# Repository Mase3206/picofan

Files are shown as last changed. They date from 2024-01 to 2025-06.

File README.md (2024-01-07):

# picofan
Picofan is a Raspberry Pi Pico-based fan controller supporting PWM fans, speed measurement, and automatic speed adjustment. A RP2040-based PCB will be published in the future.

## Hardware Requirements

### Fans

Currenly, only PWM fans are supported due to their ease of digital control. Support for voltage-controlled fans may be implemented in the future.

picofan is fan voltage-agnostic by controlling fan power with individual transistors. <!-- TODO: add info about board vcc voltages when PCB and schematics are added to repo -->

### Temperature Sensors

Fan speed can be set to adjust automatically via a default or user-defined curve with feedback from one or more temperature sensors. Only analogue sensors are supported at this time, and they must be connected to a static serial shift register, such as the [Texas Instruments CD4021B](https://www.ti.com/product/CD4021B#pps). The RP2040 has four ADCs, three of which are available to the user on the Pico; one is reserved for the on-board temperature sensor.

### Control

picofan can be controlled by a Raspberry Pi 2 or later at the moment, but support for any device with a UART interface is planned. For my development, I am using a Raspberry Pi 3b. 

## Software

picofan has two software components:
1. Pico code, written in MicroPython
2. Companion device code, written in standard Python 3

The two devices communicate via a [custom protocol](./docs/protocol.md) over UART0 and use unique addresses to identify the command sender and recipient.

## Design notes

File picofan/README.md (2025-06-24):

This folder holds the pico-side of things.

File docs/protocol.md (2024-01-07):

[Return to README](../README.md)

# Initialization Protocol

Sensor and device configuration on the Pico(s) is done through Yaml files on the companion device. Once all devices are configured in companion.py, it will communicate with the Pico(s) to initialize them. The following is an example init message:

`fd  01 02 01  01 01  04 05 06  88 fe  00 00 00 00 00`

- `fd` - begin msg
- `01` - tx addr
- `02` - rx addr
- `01` - initialize device command
- `01` - sensor/device type
- `01` - sensor/device addr
- Sensor/device parameters:
	- Fan: (this example)
		- `04` - Power control pin (out)
		- `05` - PWM pin (out)
		- `06` - Tachometer pin (in)
	- Temperature:
		- `1f` - Pico pin connected to shift register (out)
		- `01` - pin on shift register (out)
- `88` - checksum
- `fe` - end msg
- `00 ...` message filler

# Control Protocol

picofan uses a custom protocol with a simple checksum for communicating between the companion and pico(s).

Example message: `fd  01 02 03  01 01 00   7a fe  00 00 00 00 00 00 00`
- `fd` - begin msg
- `01` - tx addr
- `02` - rx addr
- `03` - command (init, init ack, set, get)
	- `01` = init
	- `02` = set
	- `03` = get
- `01` - sensor/device type (fan, temp, etc.)
	- `01` = fan
	- `02` = temp
- `01` - sensor/device addr 
- `00` - value to set/get (speed, temperature, etc.)
	- Fans:
		- `00` = speed
	- Thermal probes
		- `00` = temperature
- `7a` - checksum
- `fe` - end msg
- `00 ...` - message filler

## Checksum

The checksum is calculated in a similar manner to UPC codes:
1. Sum all evens, then multiply by 77. <sup>1</sup>
2. Sum all odds.
3. Take the mod 255 of the sum of both components. <sup>2</sup>
4. Subtract 255 by the previous result. This is your checksum. <sup>2</sup>

> [!NOTE]
> - [1] UPC codes multiply by 3.
> - [2] UPC codes use mod 10 and subtract 10 by the result.

# Examples

I have provided example messages and an ImHex Pattern Language parser in the `docs/examples` directory.

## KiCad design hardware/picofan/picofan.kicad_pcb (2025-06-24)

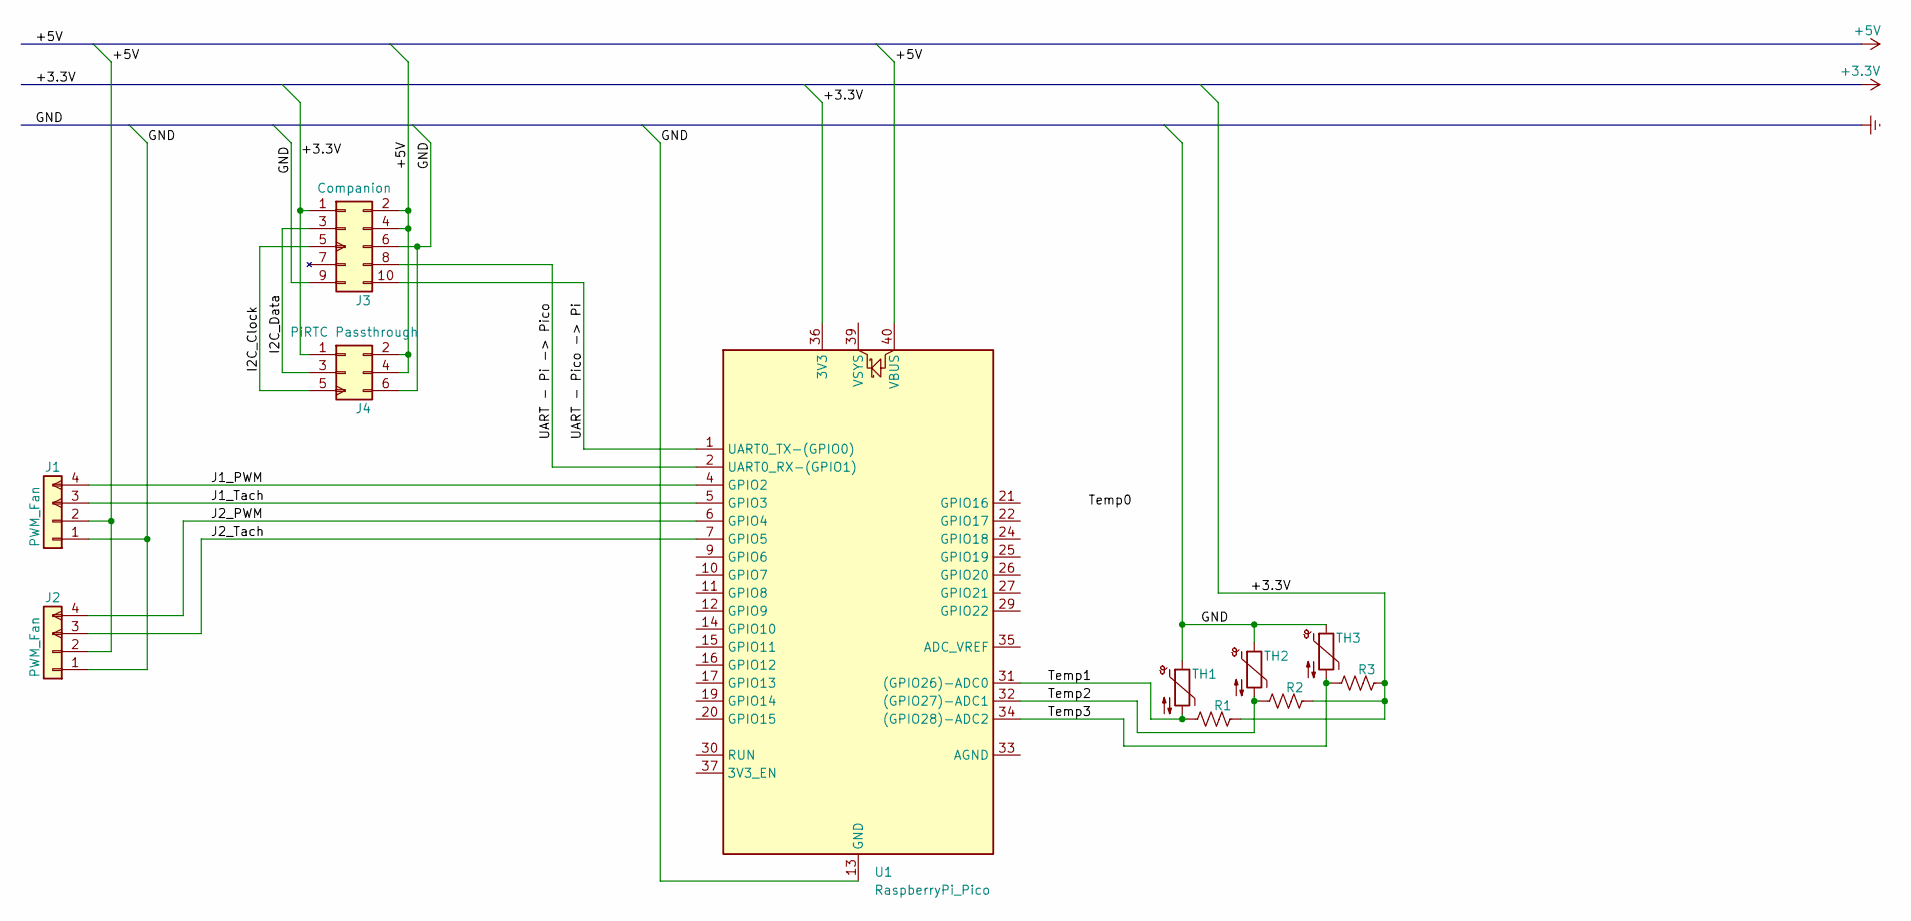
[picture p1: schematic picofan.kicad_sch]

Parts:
J1, J2: PWM_Fan; FanPinHeader_1x04_P2.54mm_Vertical
J3: Companion; IDC-Header_2x05_P2.54mm_Vertical
J4: PiRTC Passthrough; IDC-Header_2x03_P2.54mm_Vertical
R1, R2, R3: R_US; R_Axial_DIN0204_L3.6mm_D1.6mm_P5.08mm_Horizontal
TH1, TH2, TH3: Thermistor_NTC; R_Axial_DIN0204_L3.6mm_D1.6mm_P2.54mm_Vertical
U1: RaspberryPi_Pico; RaspberryPi_Pico_Common

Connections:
+3.3V: J3.1 (+3.3V), J4.1 (+3.3V), R1.2, R2.2, R3.2, U1.36 (3V3)
+5V: J1.2 (V_in), J2.2 (V_in), J3.2 (+5V), J3.4 (+5V), J4.2 (+5V), J4.4 (+5V), U1.40 (VBUS)
/I2C_Clock: J3.5 (I2C_Clk), J4.5 (I2C_Clk)
/I2C_Data: J3.3 (I2C_Data), J4.3 (I2C_Data)
/J1_PWM: J1.4 (PWM), U1.4 (GPIO2)
/J1_Tach: J1.3 (Tach), U1.5 (GPIO3)
/J2_PWM: J2.4 (PWM), U1.6 (GPIO4)
/J2_Tach: J2.3 (Tach), U1.7 (GPIO5)
/Temp1: R1.1, TH1.2, U1.31 ((GPIO26)-ADC0)
/Temp2: R2.1, TH2.2, U1.32 ((GPIO27)-ADC1)
/Temp3: R3.1, TH3.2, U1.34 ((GPIO28)-ADC2)
/UART - Pi -> Pico: J3.8 (UART_TX), U1.2 (UART0_RX-(GPIO1))
/UART - Pico -> Pi: J3.10 (UART_RX), U1.1 (UART0_TX-(GPIO0))
Earth: J1.1 (GND), J2.1 (GND), J3.6 (GND), J3.9 (GND), J4.6 (GND), TH1.1, TH2.1, TH3.1, U1.3 (GND), U1.8 (GND), U1.13 (GND), U1.18 (GND), U1.23 (GND), U1.28 (GND), U1.38 (GND)

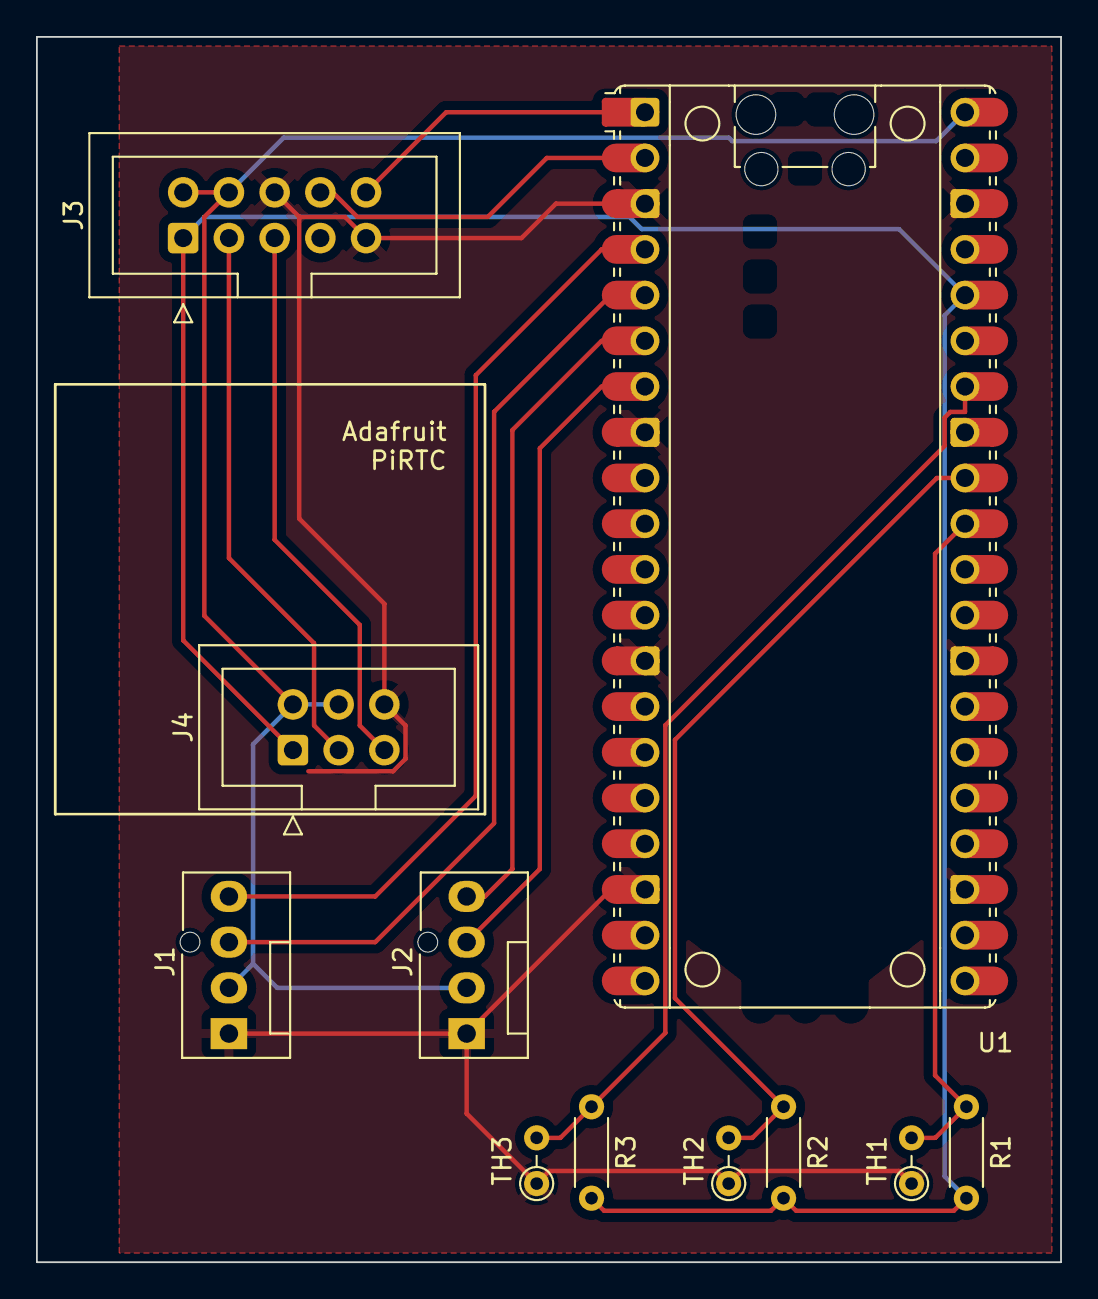
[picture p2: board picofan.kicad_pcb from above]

Board: 2 copper layers, 56.9 x 68.1 mm, 11 parts (0 on the bottom side), 14 nets.

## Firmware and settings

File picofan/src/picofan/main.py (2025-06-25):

# This is your main script.
# This is MicroPython.

# https://stackoverflow.com/questions/20923411/updating-class-variable-within-a-instance-method
# https://micropython-tve.readthedocs.io/en/counter/pyboard/general.html
import sys
import time
from enum import Enum
from typing import Any

import micropython
from machine import Pin

from picofan import com, things
from picofan.things import ThingKind

print(sys.path)

UART0 = com.JsonSerial(
    0,
    19200,
    tx=Pin(1),
    rx=Pin(2),
    parity=0,
)


class CommandType(Enum):
    SET = "set"
    GET = "get"
    REGISTER = "register"
    # UPDATE = 'update'


def handle_receive_command(uart: com.JsonSerial) -> None:
    micropython.schedule(parse_command, uart.read_json())


# set the IRQ handler
# force it to allow JsonSerial over UART for this
UART0.irq(com.JsonSerial.handle_receive_command, com.JsonSerial.IRQ_RXIDLE)  # type: ignore


def parse_command(command: dict[str, Any]) -> None:
    match command["command"]:
        case CommandType.REGISTER:
            tm.register(
                kind=command["kind"],
                address=command["addr"],
                thing=ThingKind.get_thing_class(command["kind"])(**command["kwargs"]),
            )
        case CommandType.GET:
            details = tm.get(kind=command["kind"], address=command["addr"]).__dict__
            message = {
                "kind": command["kind"],
                "addr": command["addr"],
                "details": details,
            }
            UART0.write_json(message)
        case CommandType.SET:
            setattr(
                tm.get(kind=command["kind"], address=command["addr"]),
                command["param"]["name"],
                command["param"]["value"],
            )


tm = things.ThingsManager()
"""Things manager."""
tm.register(
    ThingKind.THERMISTOR,
    0,
    things.Thermistor(Pin(26, Pin.IN)),
)
tm.register(
    ThingKind.FAN, 0, things.Fan(tach_pin=Pin(5, Pin.IN), pwm_pin=Pin(4, Pin.OUT))
)
tm.register(
    ThingKind.CURVE,
    0,
    things.FanCurve(
        therm=tm.get(ThingKind.THERMISTOR, 0), fans=[tm.get(ThingKind.FAN, 0)]
    ),
)


def main():
    while True:
        tm.get(ThingKind.CURVE, 0).update_speed()
        time.sleep(1)

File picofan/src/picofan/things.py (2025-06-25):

"""
Contains classes for thermistors, switches, knobs, fans, etc. Any "thing" that this uses for input or output. Also some software things which link two or more hardware things.
"""

from __future__ import annotations

import math
from enum import StrEnum
from typing import Any

from machine import ADC, PWM, Pin


class Thermistor:
    # Voltage Divider
    V_in = 3.3
    R_0 = 10000  # Resistor value

    # Steinhart Constants
    A = 0.001129148
    B = 0.000234125
    C = 0.0000000876741

    def __init__(self, pinObj: Pin):
        self.thermistor = ADC(pinObj)

    @property
    def temperature(self):
        # get voltage value from ADC
        V_read = self.thermistor.read_u16()
        V_out = (3.3 / 65535) * V_read

        # Calculate resistance
        R_t = (V_out * self.R_0) / (self.V_in - V_out)

        # Steinhart - Hart Equation
        temp_K = 1 / (
            (self.A + (self.B * math.log(R_t))) + (self.C * math.log(R_t) ** 3)
        )

        # Convert from Kelvin to Celsius and return
        return temp_K - 273.15


class Fan:
    tach: Pin
    pwm: PWM

    def __init__(self, tach_pin: Pin | int, pwm_pin: Pin | int):
        if isinstance(tach_pin, Pin):
            self.tach = tach_pin
        else:
            self.tach = Pin(tach_pin, mode=Pin.OUT)

        if isinstance(pwm_pin, Pin):
            self.pwm = PWM(pwm_pin, freq=1000, duty_u16=0)
        else:
            self.pwm = PWM(Pin(pwm_pin, mode=Pin.IN), freq=1000, duty_u16=0)

    @property
    def speed(self):
        return self.pwm.duty_u16() / 65535

    @speed.setter
    def speed(self, percentage: float):
        self.pwm.duty_u16(int(percentage * 100))


class FanCurve:
    """Very simple linear fan curve."""

    # fan and temperature limits
    min_temp = 30.0
    max_temp = 100.0
    min_speed = 0.3
    max_speed = 1.0

    def __init__(self, therm: Thermistor, fans: list[Fan]):
        self.therm = therm
        self.fans = fans

    @classmethod
    def calculate_speed(cls, temperature: float):
        slope = (cls.max_speed - cls.min_speed) / (cls.max_temp - cls.min_temp)
        unbound_speed = slope * temperature
        return max(cls.min_speed, min(unbound_speed, cls.max_speed))

    def update_speed(self):
        temperature = self.therm.temperature
        speed = self.calculate_speed(self.therm.temperature)
        print(f"Temperature: {temperature:.1f}, Fan speed: {speed * 100:.1f}%")
        for fan in self.fans:
            fan.speed = speed
        return speed


class ThingKind(StrEnum):
    FAN = "fan"
    THERMISTOR = "temp"
    CURVE = "curve"

    @staticmethod
    def get_thing_class(kind: ThingKind):
        match kind:
            case ThingKind.FAN:
                return Fan
            case ThingKind.THERMISTOR:
                return Thermistor
            case ThingKind.CURVE:
                return FanCurve


class ThingsManager:
    _things: dict[str, dict[int, object]]
    _instance = None

    def __init__(self):
        self._things = {
            "temp": {},
            "fan": {},
            "curve": {},
        }

    def __new__(cls, *args, **kwargs):
        """Singleton enforcement."""
        if not isinstance(cls._instance, cls):
            cls._instance = object.__new__(cls, *args, **kwargs)
        return cls._instance

    def register(self, kind: ThingKind, address: int, thing: Any) -> Any:
        """Register the thing and return its instance."""
        self._things[kind][address] = thing
        return thing

    def get(self, kind: ThingKind, address: int) -> Any:
        return self._things[kind].get(address)

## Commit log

2024-01-05 created Fan class
2024-02-19 init micropython
    [picofan.kicad_pcb, picofan.kicad_sch]
2025-06-24 create pcb
    [picofan.kicad_pcb, picofan.kicad_sch]
2025-06-24 switch to JSON for messages
2025-06-24 Implement main functionality and sensor integration for fan control
2025-06-24 I think everything should be importing correctly in picofan?
    [main.py]
2025-06-24 read and write null-terminated JSON over UART (needs to be implemented in pico side as well)
2025-06-25 objectify thermistor, fan, and fancurve
2025-06-25 switch to newline-terminated json
2025-06-25 add newline-terminated JSON uart wrapper
2025-06-25 uart irq
2025-06-25 pico-side command parsing
